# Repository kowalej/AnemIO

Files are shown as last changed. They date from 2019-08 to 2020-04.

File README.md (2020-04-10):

## Base Station Information

### Setting up and Running the Base Station
The base station (i.e. data collection) software consists of a "radio daemon" and web server, all written in Python. These libraries are meant to run on a Raspberry Pi, and have been conveniently preconfigured as Docker containers. To get started you will need to flash your Raspberry Pi with an appropriate image and ensure Docker is installed on it. After that it will just be a matter of copying the source files to the device, and starting up the containers. Below I have included instructions on how to set everything up using a Rasberry Pi image distribution called [Hypriot](https://blog.hypriot.com/). You could alternatively use the defacto Raspbian (Lite) image or another OS like [Balena](https://www.balena.io/os/). Hypriot is my preference because it is optimized to run Docker containers and is easy to configure in conjunction with their config files and [flash tool](https://github.com/hypriot/flash).

Note: If you don't want to use Hypriot you may start at the  official [Raspberry Pi image installation guide](https://www.raspberrypi.org/documentation/installation/installing-images/README.md) for instructions on setting up the Pi's basic image and enabling Wifi. Once you can connect to the Pi through SSH, you can follow this guide to manually install Docker https://blog.alexellis.io/getting-started-with-docker-on-raspberry-pi.

If you already have a Pi up and running and know how to setup Docker, you can probably skip these instructions.

### Raspberry Pi Hypriot Setup

#### Flash Pi on Windows with Etcher or Rufus
1. Head over to the [Hypriot downloads](https://blog.hypriot.com/downloads/) page and grab the latest distribution - as of writing I am using [1.12.0](https://github.com/hypriot/image-builder-rpi/releases/download/v1.12.0/hypriotos-rpi-v1.12.0.img.zip).
2. After downloading, extract the .zip so you can see the .img file which you will be flashing to your device.
3. Before flashing please copy the template file user-data.yml from the `\src\raspi-base\raspi-config-files` folder of this repo to a temporary location. You will need to edit this copy of `user-data.yml` before flashing (mainly to just replace the Wifi SSID / password).
4. Download and install [Balena Etcher (Recommended)](https://www.balena.io/etcher/) or [Rufus](https://rufus.ie/). Both are easy to use and you will be able to just select the extracted Hypriot .img file and flash it onto your device.
5. After your device is flashed, you should be able to browse the SD card on your computer (usually F: drive, where you flashed to). Browse this device and edit the existing user-data file with the contents of your modified user-data.yml file from earlier.
6. Copy the contents `\src\raspi-base\raspi-config-files\config.txt` to the config.txt file on the SD card.
7. Get the current date time by running the powershell script `(Get-Date).ToUniversalTime().ToString("yyyy-MM-dd HH:mm:ss")`.
8. Copy that date time into fake-hwclock.data on the SD card. You could also just have manually edited this file, but running the script is safer so that you get the proper date time format.
9. Safely eject your SD card using the system tray tool!
10. You are now done, and should be able to boot from this SD card by inserting it into your Pi and powering the Pi on.

#### Flash Pi on Linux/Mac with Hypriot Flash Utility
1. Head over to the [Hypriot downloads](https://blog.hypriot.com/downloads/) page and grab the latest distribution - as of writing I am using [1.12.0](https://github.com/hypriot/image-builder-rpi/releases/download/v1.12.0/hypriotos-rpi-v1.12.0.img.zip).
2. After downloading, extract the .zip so you can see the .img file which you will be flashing to your device.
3. Before flashing please copy the template file user-data.yml from the `\src\raspi-base\raspi-config-files` folder of this repo. You will need to edit this copy of `user-data.yml` before flashing (mainly to just replace the Wifi SSID / password).
4. Acquire the Hypriot flash tool. You can install using this script:
```
curl -LO https://github.com/hypriot/flash/releases/download/2.6.0/flash
sudo chmod +x flash
sudo mv flash /usr/local/bin/flash
```
5. Flash your device. With a terminal in the directory that contains your extracted image and modified user-data file:
```
flash --userdata user-data.yml --device <device_here> hypriotos-rpi-v1.12.0.img
```
6. You are now done, and should be able to boot from this SD card by inserting it into your Pi and powering the Pi on.

#### Access and Complete Device Setup
Now that your device is flashed with your custom boot config, you should be able to access it over the network. You can try `ping anemio-pi.local` or `ping anemio-pi` and should see some network loopback if you device is connected. Please note, the intial boot and setup of the device may take a few minutes to complete, so if you just inserted the fresh SD card into the Pi, you may have to wait a few minutes. 

**Future notes:**
If you are on Windows (like me) and want to use the Hypriot flash tool - you may be able to use it directly via WSL-2 (Windows Subsystem for Linux). However, you would probably have to follow this guide carefully to properly configure access to the card reader (https://github.com/jovton/USB-Storage-on-WSL2).

## Weather Station Information

### Arduino Libraries in Use
* Wire (built in I2C library) - [See Arduino Reference Site](https://www.arduino.cc/en/Reference/Wire)
* BME280 and BMP280 Digital Pressure Sensor Library (Version 0.0.2) - *by Gregor Christandl* - [Source Code Here](https://bitbucket.org/christandlg/bmx280mi)
* Adafruit Unified Sensor Library (Version 1.0.3) - *by Adafruit* - [Source Code Here](https://github.com/adafruit/Adafruit_Sensor)
* Adafruit DHT-sensor-library (Version 1.3.7) - *by Adafruit* - [Source Code Here](https://github.com/adafruit/DHT-sensor-library)
* SerialDebug (Version 0.9.2) - *by Joao Lopes* - [Source Code Here](https://github.com/JoaoLopesF/SerialDebug)

### Tools in Use
* [SerialDebugApp](https://github.com/JoaoLopesF/SerialDebug/tree/master/SerialDebugApp) for helping read output from SerialDebug library.
* [Visual Micro](https://www.visualmicro.com/) for working with Arduino in Visual Studio.
    
## Hardware Information

### Sensors / Peripherals
<div class="parts-table">

| Part Name | Function / Description | Data Sheet | Purchase Sources / Prices |
|---|---|---|---|
| AMBI (GA1A1S201WP) | **Ambient light sensor.**<br>- Wide operating temperature range (-40 - +85 C)<br>- Gives consistent and sensible output readings (0 is pitch black, maximum sunlight is 1023)<br>- Won't over saturate in daylight | [GA1A1S201WP OPIC Light Detector (Mouser.ca)](https://www.mouser.ca/datasheet/2/365/GA1A1S201WP_Spec-184717.pdf) | [Modern Device](https://moderndevice.com/product/ambi-light-sensor/) ($3 USD) |
| BMP280 (BME280) | **Barometric pressure sensor.**<br>- ±1.0°C accuracy<br>- ±1 hPa accuracy<br>- I2C or SPI interface<br>- Altitude, ±1 meter accuracy | [BST-BMP280-DS001 (Bosch.com)](https://ae-bst.resource.bosch.com/media/_tech/media/datasheets/BST-BMP280-DS001.pdf) | [Creatron](https://www.creatroninc.com/product/bmp280-barometric-sensor-300-to-1100hpa/) ($7.90 CAD)<br>[Adafruit](https://www.adafruit.com/product/2651) ($9.95 USD)<br>[Sparkfun - BME280](https://www.sparkfun.com/products/13676) ($19.95 USD)|
| LSM303DLHC | **Compass / accelerometer.**<br>- Compass and accelerometer all in one<br>- I2C interface<br>- Triple axis sensing | [LSM303DLHC (Adafruit.com)](https://cdn-shop.adafruit.com/datasheets/LSM303DLHC.PDF) | [Adafruit](https://www.adafruit.com/product/1120) ($14.95 USD)|
| MH-RD / FC-37 / YL-83 | **Rain sensor.**<br>- Simple interface<br>- Adjustable sensitivity<br>| [No datasheet but info available from Random Nerd Tutorials](https://randomnerdtutorials.com/guide-for-rain-sensor-fc-37-or-yl-83-with-arduino/) | [Creatron](https://www.creatroninc.com/product/water-rain-sensor/?search_query=rain+sensor&results=10) ($5.99 CAD)|
| DHT-22 | **Temperature / humidity sensing.**<br>- 2.5mA max current use during conversion<br>- 0-100% humidity readings with 2-5% accuracy<br>- 40 to 80°C temperature readings ±0.5°C accuracy<br>- No more than 0.5 Hz sampling rate (once every 2 seconds) | [DHT22 Datasheet (Sparkfun.com)](https://www.sparkfun.com/datasheets/Sensors/Temperature/DHT22.pdf) | [Creatron](https://www.creatroninc.com/product/dht22-humidity-and-temperature-sensor/) ($13.00 CAD)<br>[Adafruit](https://www.adafruit.com/product/385) ($9.95 USD)<br>[Sparkfun](https://www.sparkfun.com/products/10167) ($9.95 USD)|
| AS5040 | **Wind direction (magenetic rotary encoder).**<br>- Absolute positioning<br>- Contact free<br>- Very long life<br> - Multi interface | [AS5040 Datasheet (Digikey.com)](https://media.digikey.com/pdf/Data%20Sheets/Austriamicrosystems%20PDFs/AS5040.pdf) | [Digikey](https://www.digikey.ca/product-detail/en/ams/AS5040-SS_EK_AB/AS5040-EK-AB-ND/2339617) ($23.83 CAD)|
| Rev. P wind sensor | **Wind speed sensor.**<br>- Wind speeds measured: 0-150 MPH<br>- Ambient temperature compensation<br>- Accuracy of +/- 3 MPH (estimated) | [No Datasheet but info available here](https://moderndevice.com/uncategorized/calibrating-rev-p-wind-sensor-new-regression/?preview=true) | [Modern Device](https://moderndevice.com/product/wind-sensor-rev-p/) ($24 USD)|
| OCR TM | **Water temperature (thermistor).**<br>- Very inexpensive<br>- Simple interface (it's basically a resistor).<br>- Fairly accurate| [No datasheet but info available from Adafruit](https://learn.adafruit.com/thermistor/using-a-thermistor) | [Amazon.ca](https://www.amazon.ca/Ocr-Waterproof-Digital-Thermal-Temperature/dp/B0185P4MVO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) ($15.99 CAD per 5 units)|
| RFM69HCW  | **Transceiver radio for data transfer (x2).**<br>- Inexpensive<br>- Simple to use<br>- Low power consumption<br>- Long range (at least 1km, up to 10+ km with proper configuration)| [RFM69HCW ( Adafruit.com)](https://cdn-shop.adafruit.com/product-files/3076/RFM69HCW-V1.1.pdf) | [Adafruit.com](https://www.adafruit.com/product/3070) ($9.95 USD each)<br>[Digikey.ca](https://www.digikey.ca/product-detail/en/adafruit-industries-llc/3070/1528-1665-ND/6005355) ($14.15 CAD each)|

</div>

### Microcontrollers
<div class="parts-table">

| Device Name | Function / Description | Guide | Purchase Sources / Prices |
|---|---|---|---|
| Arduino Mega  | **Main controller for data collection.**<br>- Tonnes of IO<br>- Lots of memory (relative to other microcontrollers)<br>- Good power handling | [Arduino.cc](https://www.arduino.cc/) | [Amazon.ca (clone)](https://www.amazon.ca/keyestudio-Board-Cable-Compatible-Arduino/dp/B016JWNYBE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) ($19.99 CAD)<br>[Arduino.cc (official)](https://store.arduino.cc/usa/mega-2560-r3) ($38.50 USD)|
| Raspberry Pi Zero W | **Data receiving, relay, storage, and web server.**<br>- Built in WIFI<br>- Very powerful<br>- Inexpensive | [Arduino.cc](https://www.arduino.cc/) | [Creatron](https://www.creatroninc.com/product/raspberry-pi-zero-w/) ($28.00 CAD)<br>[Amazon.com](https://www.amazon.com/Raspberry-Pi-Zero-Wireless-model/dp/B06XFZC3BX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) ($18.89 USD)|

</div>

### Misc
<div class="parts-table">

| Device Name | Function / Description | Guide | Purchase Sources / Prices |
|---|---|---|---|
| SanDisk Ultra 32GB  | **SD card for Raspberry Pi.**<br>- Cheap<br>- Lots of reliable storage (32 GB)| N/A | [Amazon.ca](https://www.amazon.ca/gp/product/B073JWXGNT/ref=ppx_yo_dt_b_asin_title_o00_s00?ie=UTF8&psc=1) ($11.47 CAD) |
| ACJ D7S | **Battery power for weather station.**<br>- 12 V<br>- 7Ah<br>- Inexpensive| [AJCBattery.com](https://ajcbattery.com/product/ajc-12v-7ah/#pane-1) | [Amazon.ca](https://www.amazon.ca/gp/product/B00A82GD60/ref=ppx_yo_dt_b_asin_title_o02_s00?ie=UTF8&psc=1) ($25.89 CAD)|
| NOMA 2.5W | **Solar power for weather station.**<br>- 2.5W<br>- Built-in diode<br> - Using because on sale for $10 CAD / panel | N/A | [CanadianTire.ca](https://www.canadiantire.ca/en/pdp/noma-2-5w-solar-battery-maintainer-0110010p.html#srp) ($34.99 CAD, was on sale for $9.99 CAD)|

</div>

*Note that alternative SD cards, batteries, and solar panel(s) may be used. SD cards should be at least 4GB if you want to have some data storage capabilities for the Raspberry Pi. A large capacity battery may also be used, if available. The solar panels used on my setup were chosen because they were a good price, but panel(s) with greater power output would be recommended. 

<style>
.parts-table table tr td:nth-child(1) {
        vertical-align: text-top;
        width: 25%;
        max-width: 100px;
}
.parts-table table tr td:nth-child(2) {
        vertical-align: text-top;
        width: 40%;
        max-width: 100px;
}
.parts-table table tr td:nth-child(3) {
        vertical-align: text-top;
        width: 15%;
        overflow: hidden;
        max-width: 100px;
}
.parts-table table tr td:nth-child(4) {
        vertical-align: text-top;
        width: 20%;
        overflow: hidden;
        max-width: 100px;
}
</style>

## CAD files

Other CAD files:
3dparts/WindSensorHarness.skp

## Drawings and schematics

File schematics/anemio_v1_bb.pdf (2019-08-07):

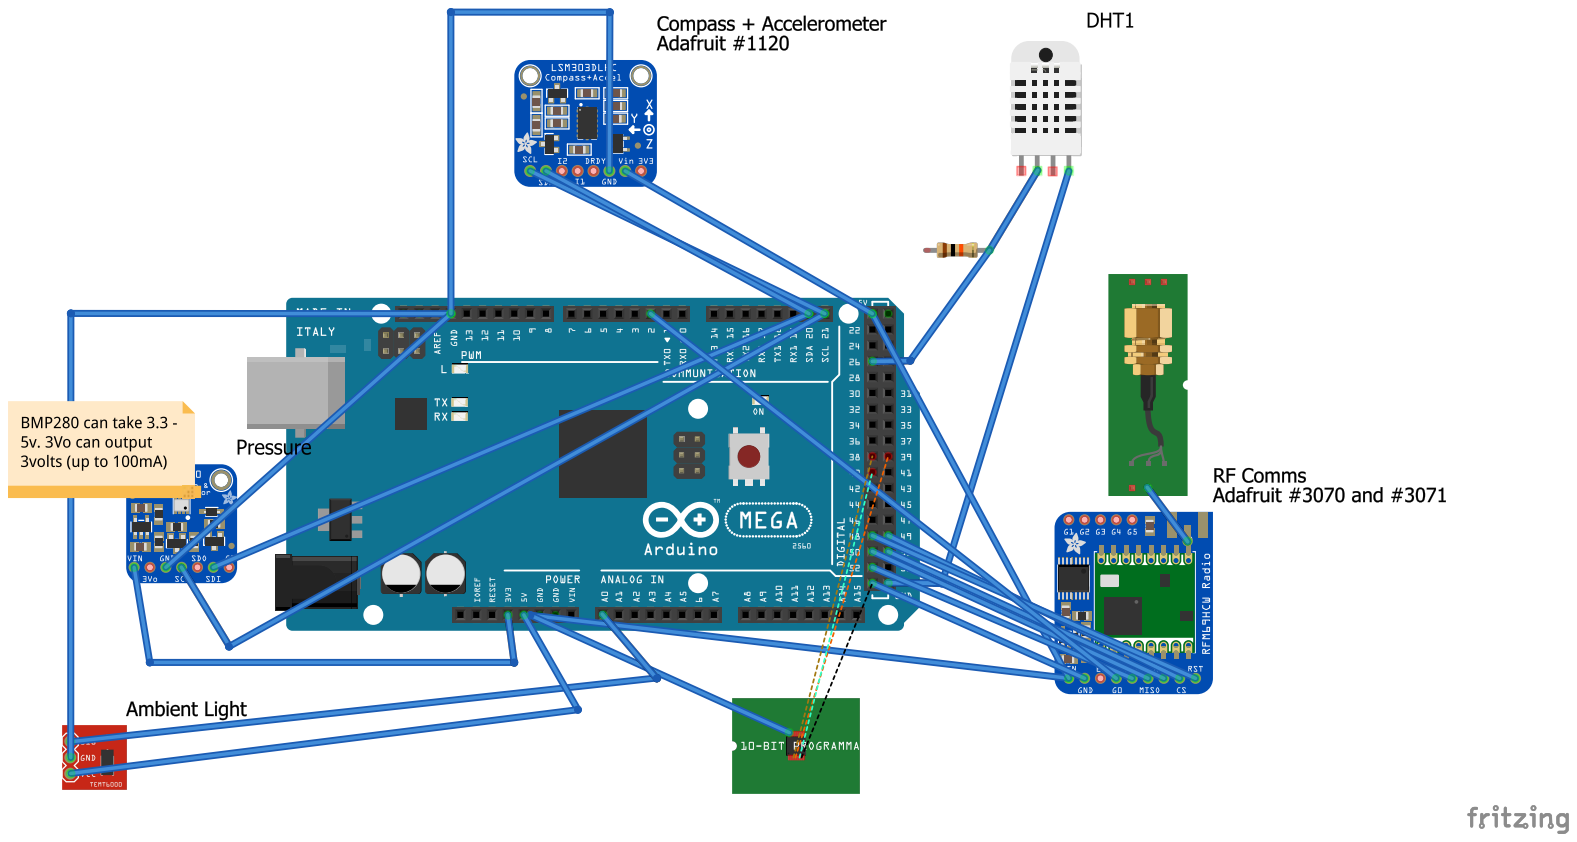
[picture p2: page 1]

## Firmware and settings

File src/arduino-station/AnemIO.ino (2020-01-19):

#pragma region SerialDebug Settings

// SerialDebug Library

// Disable all debug ? Good for release builds (production)
// as nothing from SerialDebug is compiled, zero overhead :-)
// For it just uncomment the DEBUG_DISABLED
// #define DEBUG_DISABLED true

// Define the initial debug level here (uncomment to do it)
#define DEBUG_INITIAL_LEVEL DEBUG_LEVEL_VERBOSE

// Disable SerialDebug debugger ? No more commands and features as functions and globals
// Uncomment this to disable it
#define DEBUG_DISABLE_DEBUGGER false

// Disable auto function naming (good if your debug message already contains it)
//#define DEBUG_AUTO_FUNC_DISABLED true

// Force debug messages to use flash?
// Disable native Serial.printf (if using)
// Good for low memory, due to flash use, but is slowwer and doesn't use macros
//#define DEBUG_USE_FLASH_F true

#if defined(ARDUINO_AVR_ADK)
#define SERIAL_SPEED 250000
#elif defined(ARDUINO_AVR_MEGA)
#define SERIAL_SPEED 250000
#elif defined(ARDUINO_AVR_MEGA2560)
#define SERIAL_SPEED 115200
#elif defined(ARDUINO_SAM_DUE)
#define SERIAL_SPEED 250000
#elif defined(ARDUINO_SAMD_ZERO)
#define SERIAL_SPEED 250000
#elif defined(ARDUINO_ARC32_TOOLS)
#define SERIAL_SPEED 250000
#elif defined ESP8266 || defined ESP32
#define SERIAL_SPEED 250000
#else
#define SERIAL_SPEED 115200
#endif

#include "SerialDebug.h" 

#pragma endregion

#include "AnemioStation.h"

AnemioStation station;

void setup()
{
	// Set serial rate.
	Serial.begin(SERIAL_SPEED);

#ifdef __AVR_ATmega32U4__ 
	while (!Serial) {} // Wait for serial connection to open (only necessary on some boards).
#else
	delay(500); // Wait a fixed time for serial.
#endif
	station.setup();
}

void loop()
{
	// Handle Serial Debug.
	debugHandle();

	// Main station operation.
	// 1. Check sensor statuses.
	// 2. Collect samples.
	// 3. Send over radio.
	station.loop();
}

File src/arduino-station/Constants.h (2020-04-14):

// Constants.h

#ifndef CONSTANTS_H
#define CONSTANTS_H

#if defined(ARDUINO) && ARDUINO >= 100
#include "arduino.h"
#else
#include "WProgram.h"
#endif

#include <RFM69.h>

#define GET_BUFFER_SIZE(sensorRateHz, maxSendMs) (size_t(maxSendMs/1000 * sensorRateHz)) 

namespace {
	const uint8_t MCU_VOLTAGE = 5;

	const uint16_t RADIO_SEND_INTERVAL_MS = 5000; // Maximum time between transmitting consecutive sample sets over the radio.
	const uint16_t RADIO_RECEIVE_INTERVAL_MS = 15000; // Maximum time between receiving commands over the radio.
	const uint16_t RADIO_RECEIVE_WAIT_MS = 1500; // Default time to wait for command from base station.
	const uint16_t RADIO_SLEEP_MODE_RECEIVE_WAIT_MS = 2000; // How long check for wake message before sleeping again.

	const uint16_t SLEEP_MODE_SLEEP_TIME_MS = 15000; // How long to sleep before checking for message.

	// Ambient light sensor.
	const uint8_t AMBIENT_LIGHT_UPDATE_RATE_HZ = 1; // Update rate of light sensor.
	constexpr float AMBIENT_LIGHT_STATE_UPDATE_RATE_HZ = 0.2; // Update rate of the ambient light state. (aggregated value).
	const uint8_t AMBIENT_LIGHT_ANALOG_READ_SAMPLE_COUNT = 50; // Number of times we should do an analog read from the ambient light sensor (we will average the samples).
	const uint8_t AMBIENT_LIGHT_SENSOR_INPUT_PIN = A2;
	const uint32_t AMBIENT_LIGHT_SENSOR_RESISTANCE_OHM = 100000; // This is the value of the internal resistor in the sensor.

	// Battery info (percent charge).
	constexpr uint8_t BATTERY_INFO_UPDATE_RATE_HZ = 0.1666f; // Update rate of battery level.
	const uint8_t BATTERY_LEVEL_INPUT_PIN = A6; // Battery voltage divider pin.
	const uint16_t BATTERY_LEVEL_R1_OHMS = 22000; // Impedence of "R1" for voltage divider.
	const uint16_t BATTERY_LEVEL_R2_OHMS = 10000; // Impedence of "R2" for voltage divider.
	const uint16_t BATTERY_DISCHARGED_MILLIVOLTS = 6200; // Voltage of battery when we consider it discharged (0%).
	const uint16_t BATTERY_FULLCHARGED_MILLIVOLTS = 12600; // Voltage of battery when it is considered fully charged (100%).

	// Compass / accelerometer sensor.
	const uint8_t COMPASS_ACCELEROMETER_UPDATE_RATE_HZ = 2; // Update rate of compass / accelerometer sensor.

	// Pressure / temperature sensor.
	const uint8_t PRESSURE_UPDATE_RATE_HZ = 1; // Update rate of pressure sensor.
	const uint8_t BMP280_IC2_ADDRESS = 0x76; // Should be set to 0x77 if pushing 5v to SDO.

	// Rain sensor.
	const uint8_t RAIN_UPDATE_RATE_HZ = 2; // Update rate of rain sensor.
	constexpr float RAIN_STATE_UPDATE_RATE_HZ = 0.2; // Update rate of the rain state (aggregated value).
	const uint8_t RAIN_ANALOG_READ_SAMPLE_COUNT = 50; // Number of times we should do an analog read from the rain sensor (we will average the samples).
	const uint8_t RAIN_SENSOR_INPUT_PIN = A1; // Analog input pin for the rain sensor.

	// Temperature / humidity sensor.
	const uint8_t TEMPERATURE_HUMIDITY_UPDATE_RATE_HZ = 1; // Update rate of temperature/humdity sensor.
	const uint8_t TEMPERATURE_HUMIDITY_INPUT_PIN = 22; // Digital input pin for the temperature humdity sensor.
	const uint8_t TEMPERATURE_HUMIDITY_FAULT_MAX = 25; // Consecutive read faults, before taking offline.

	// Wind direction sensor.
	const uint8_t WIND_DIRECTION_UPDATE_RATE_HZ = 1; // Update rate of wind direction sensor (rotary encoder).
	const uint8_t WIND_DIRECTION_FAULT_MAX = 25; // Consecutive read faults, before taking offline.
	const uint8_t WIND_DIRECTION_SENSOR_CLK_PIN = 7; // Use a PWM "clock" pin.
	const uint8_t WIND_DIRECTION_SENSOR_CS_PIN = 32; // Chip select (digital pin, out).
	const uint8_t WIND_DIRECTION_SENSOR_DO_PIN = 33; // Data pin (in).
	const uint8_t WIND_DIRECTION_ZERO_NUM_SAMPLES = 50; // Number of times to samples position while calibrating.
	const uint8_t WIND_DIRECTION_ZERO_TIME_SECONDS = 5; // Time for user to hold wind sock in place while sampling.

	// Wind speed sensor.
	const uint8_t WIND_SPEED_UPDATE_RATE_HZ = 1; // Update rate of wind speed sensor.
	const uint8_t WIND_SPEED_ANALOG_READ_SAMPLE_COUNT = 50; // Number of times we should do an analog read from the wind speed sensor (we will average the samples).
	const uint8_t WIND_SPEED_SENSOR_SPEED_INPUT_PIN = A3;
	const uint8_t WIND_SPEED_SENSOR_TEMPERATURE_INPUT_PIN = A4;
	const float WIND_SPEED_SENSOR_ZERO_WIND_VOLTAGE = 1.340; // This may vary slightly from sensor to sensor.
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

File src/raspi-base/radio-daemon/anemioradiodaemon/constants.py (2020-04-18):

from enum import Enum
import os

# We will try to load environment vars. This is helpful if we are using a .env file, versus setting all our environment variables.
from dotenv import load_dotenv
from pathlib import Path
env_path = os.getenv('ANEMIO_ENVIRONMENT_FILE_PATH', None)
if env_path is None:
    env_path = Path('.') / '.prod.env'
try:
    load_dotenv(env_path, verbose=True)
except IOError:
    try:
        load_dotenv()
    except IOError:
        pass

# Additional "buffer" to add to our wait times (in case station is busy processing).
TIME_BUFFER = 1.5

# Average time it takes to receive data after it was sent by station (i.e. lag).
DEFAULT_RADIO_DELAY_MS = 20

# How often does the station check for radio commands during normal operation.
RADIO_RECEIVE_INTERVAL_MS = 15000
# Time we send radio commands to ensure our station received them.
RADIO_COMMAND_RETRY_NUM = int(TIME_BUFFER * RADIO_RECEIVE_INTERVAL_MS / 1000)  # Divide by radio.py CSMA limit time ms.

# How often does the station check for radio commands during sleep mode.
SLEEP_MODE_SLEEP_TIME_MS = 15000
# Time we send radio commands to ensure our station received them.
WAKE_COMMAND_RETRY_NUM = int(TIME_BUFFER * SLEEP_MODE_SLEEP_TIME_MS / 1000)  # Divide by radio.py  CSMA limit time ms.

RADIO_INITIALIZE_RETRY_NUM = 42

# Sleep time will be 50 ms (try to send command or get new set of packets every 50 ms).
DEFAULT_TRANSRECEIVE_SLEEP_SEC = 50.0 / 1000.0

# Database.
DEFAULT_DB_NAME = os.getenv('ANEMIO_DB_NAME', 'anemio.db')

# Radio details.
RADIO_STATION_NODE_ID = 97  # Station node number.
RADIO_BASE_NODE_ID = 87  # Base station node number.
RADIO_NETWORK_ID = 223  # Radio network.
ENCRYPT_KEY = os.getenv('ANEMIO_ENCRYPT_KEY', 'J53Y25U5D8CE79NO')  # Encrypting data makes system more reliable.

# File log parameters.
LOG_FILE_MAX_SIZE_MB = os.getenv('ANEMIO_LOG_FILE_MAX_SIZE_MB', 5)
LOG_FILE_NAME = '/data/anemio/anemio.log'
LOG_FILE_BACKUP_COUNT = os.getenv('ANEMIO_LOG_FILE_BACKUP_COUNT', 2)

# Email parameters.
EMAIL_FROM = os.getenv('ANEMIO_EMAIL_FROM', '')
EMAIL_TO = os.getenv('ANEMIO_EMAIL_TO', '')
EMAIL_HOST = os.getenv('ANEMIO_EMAIL_HOST', '')
EMAIL_PORT = os.getenv('ANEMIO_EMAIL_PORT', '')
EMAIL_USER = os.getenv('ANEMIO_EMAIL_USER', '')
EMAIL_PASSWORD = os.getenv('ANEMIO_EMAIL_PASSWORD', '')

# Rate limiting.
EMAIL_RATE = os.getenv('ANEMIO_EMAIL_RATE', '')
EMAIL_RATE_SECONDS = os.getenv('ANEMIO_EMAIL_RATE_SECONDS', '')
EMAIL_RATE_BURST = os.getenv('ANEMIO_EMAIL_RATE_BURST', '')

COMPACT_MESSAGES_START = "^^"
COMPACT_MESSAGES_END = "$$"

# Maximum allowed time to receive no radio messages, until reporting that we are in unreachable state.
MAX_NO_RECEIVE_SECONDS = 25


class Devices(Enum):
    AMBIENT_LIGHT = 0
    BATTERY_INFO = 1
    COMPASS_ACCELEROMETER = 2
    PRESSURE = 3
    RAIN = 4
    TEMPERATURE_HUMIDITY = 5
    WATER_TEMPERATURE = 6
    WIND_DIRECTION = 7
    WIND_SPEED = 8
    TOTAL = 9


class SensorCategory(Enum):
    AMBIENT_LIGHT_VALUES = 0
    AMBIENT_LIGHT_STATE = 1
    BATTERY_LEVEL = 2
    COMPASS_XYZ = 3
    COMPASS_HEADING = 4
    ACCELEROMETER_XYZ = 5
    PRESSURE_PRESSURE = 6
    PRESSURE_TEMPERATURE = 7
    PRESSURE_ALTITUDE = 8
    RAIN_VALUES = 9
    RAIN_STATE = 10
    TEMPERATURE = 11
    HUMIDITY = 12
    WATER_TEMPERATURE = 13
    WIND_DIRECTION = 14
    WIND_SPEED = 15
    TOTAL = 16


class RadioCommands(Enum):
    INITIALIZE = 0
    SETUP_START = 1
    REPORT_SETUP_STATE = 2
    SETUP_FINISH = 3
    REPORT_ONLINE_STATE = 4
    SAMPLES_START = 5
    SAMPLE_GROUP_DIVIDER = 6
    SAMPLE_WRITE = 7
    SAMPLES_FINISH = 8
    SLEEP = 9
    WAKE = 10
    RESTART = 11
    CALIBRATE = 12


class StationState(Enum):
    UNKNOWN = -1  # Damemon started, cannot determine state.
    OFFLINE = 0  # Station is off - intentionally in transit or otherwise.
    SETUP_BOOT = 1  # Station is setting up (initial launch).
    ONLINE = 2  # Normal operation.
    RESTART_REQUESTED = 3  # Restart requested, awaiting completion, will transition to RESTARTING, then SETUP_BOOT / ONLINE.
    RESTARTING = 4  # Station acknowledged restart request, now we are awaiting it.
    SLEEP_REQUESTED = 5  # Sleep mode requested, awaiting completion, will transition to SLEEPING.
    SLEEPING = 6  # Save power - station will check for command once and awhile.
    WAKE_REQUESTED = 7  # Wake requested, awaiting completion, will transition to ONLINE.
    SETUP_WAKE = 8  # Station is setting up (from boot).
    CALIBRATE_REQUESTED = 9  # Calibrate mode requested, awaiting completion, will transition to CALIBRATING.
    CALIBRATING = 10,  # Station acknowledged calibration requested, now it is calibrating.
    UNREACHABLE = 11  # No signal has been recieved for awhile.

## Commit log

2019-07-24 Working pressure sensor.
2019-07-26 Refactoring + add rain sensor and boilerplate for temp/humidity.
2019-07-29 Clean up general code structure. Fix debug serial printing. Added temperature / humidity sensor readings.
    [AnemIO.ino, Constants.h]
2019-08-02 Added ambient light sensor, and swapped to a ring buffer implementation.
    [Constants.h]
2019-08-03 Update wind speed temperature correction code.
    [AnemIO.ino, Constants.h, WindSpeedProvider.cpp]
2019-08-07 Update readme and mostly implement compass / accelerometer.
    [anemio_v1.fzz]
2019-08-07 Finish adding compass / accelerometer.
2019-08-10 Code cleanup + add water temperature sensor.
    [anemio_v1.fzz]
2019-08-10 Update circuit diagram.
    [anemio_v1.fzz]
2019-08-13 Calculate lux from ambient light sensor and cleanup code.
    [WindSensorHarness.skp, WindSensorHarness.stl, WindSensorHarnesss.stl]
2019-08-16 Fix lux calculation, update circuit diagram.
    [anemio_v1.fzz]
2019-08-19 Update README to include more parts info and start setting up base station code.
    [anemio_v1.fzz]
2019-08-20 Initial setup of radio.
    [anemio_v1.fzz]
2019-08-23 Fix some code.
    [anemio_v1.fzz]
2019-12-22 Working radios.
    [anemio_v1.fzz]
2020-01-19 Adding wind direction calibration.
2020-02-09 Fix bugs in daemon and station.
    [Constants.h, radiodaemon.py]
2020-03-23 Good filtering and sorting.
2020-04-09 Working Hypriot config.
    [config.txt]
2020-05-01 Sample group dividers with types.
